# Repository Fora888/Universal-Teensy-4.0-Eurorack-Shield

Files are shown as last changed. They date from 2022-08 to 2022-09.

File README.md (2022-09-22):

# Universal-Teensy-4.0-Eurorack-Shield
This PCB is designed to piggyback onto a perfboard, to eneable easy designing and building of custom DSP based eurorack modules. It features two 24-bit audio input and two 24-bit audio output channels. The corresponding DAC and ADC are wired up to easily work with the PJRC audio library. 

## Components
All components minus the Teensy 4.0 microcontroller and PCB can be easily ordered with the mouser project below
https://www.mouser.com/ProjectManager/ProjectDetail.aspx?AccessID=7126760366

The PCB can be ordered at a PCB manufacturer of your choice. I ordered mine at Aisler.

## Building Notes
I recommend to reflow solder this board, since most pads are really close to eachother. If you however choose to handsolder, my advice is to go from smallest to largest component.

The headers on the teensy need to be on the same side as the USB port, so that the USB port faces towards the PCB when mounted. This is done to allow utilisation of the backside pins of the Teensy. There are also 5V and GND markings on the PCB to ensure correct orientation.

## Schematic
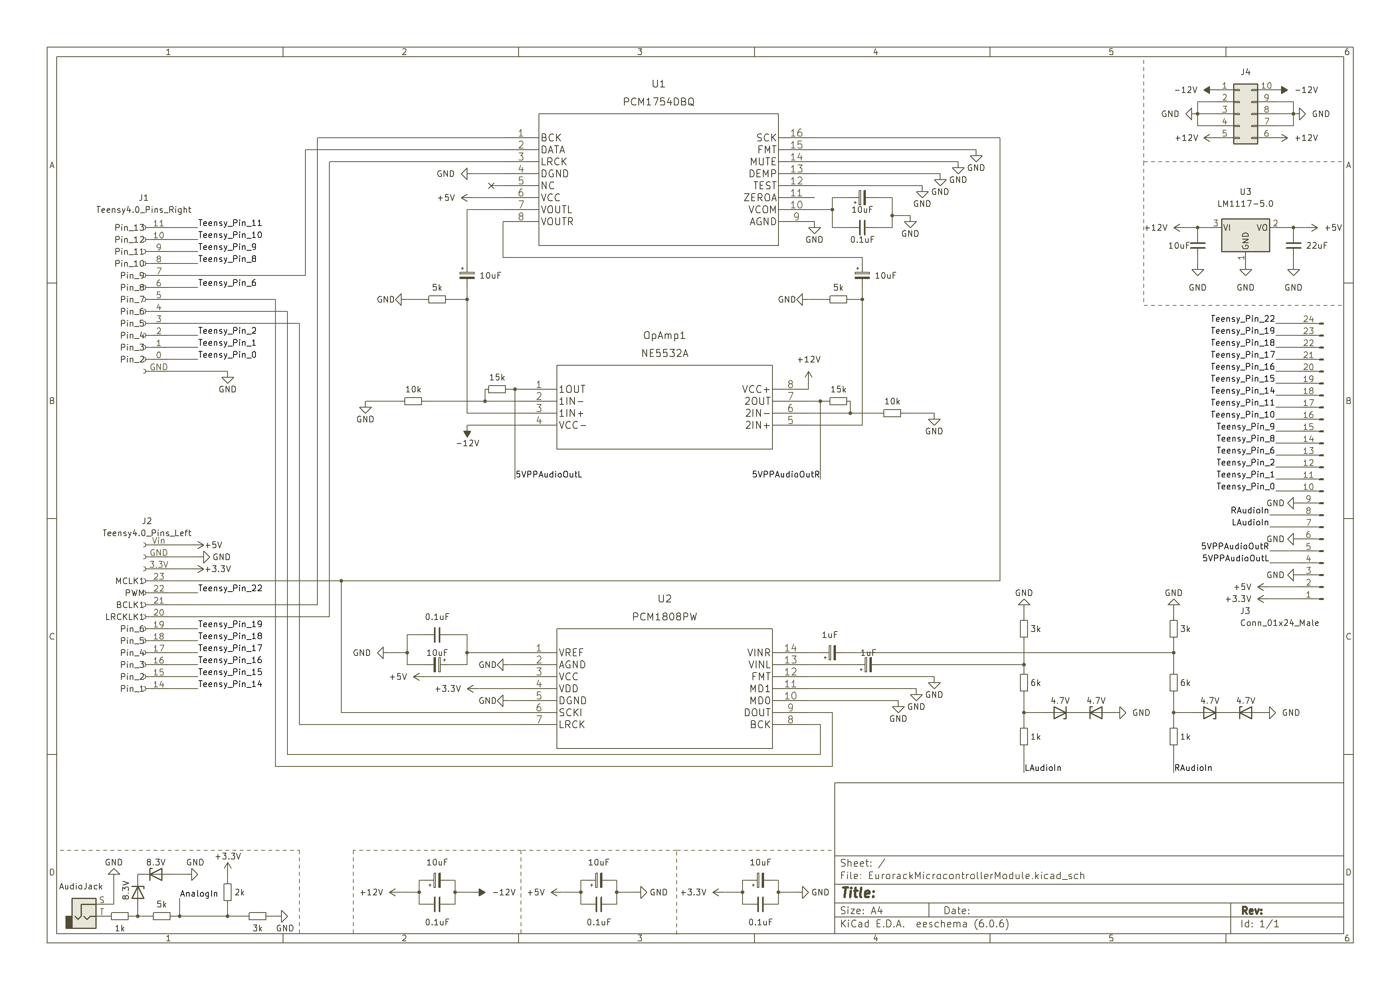
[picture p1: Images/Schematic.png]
Schematic


## 3DRender
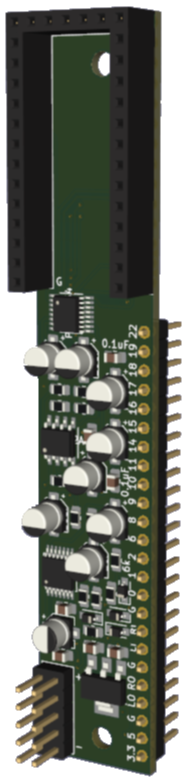
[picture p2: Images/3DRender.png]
3DRenderg


## Example Modules
There are currently no working examples. I am however working on a wavetable module based on this board. I'll add it as soon as it's finished.

## Disclaimer
The Updated PCB has yet to be build and is therefore not guaranteed to work. The last commit that was build and tested is [df5ed19](https://github.com/Fora888/Universal-Teensy-4.0-Eurorack-Shield/tree/df5ed198294865db2b968ab182dcd4eb55e7e81e)

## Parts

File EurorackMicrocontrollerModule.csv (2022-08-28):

Source: | C:\Users\Florian\Documents\KiCad\EurorackMicrocontrollerModule\EurorackMicrocontrollerModule.kicad_sch
Date: | 04.08.2022 11:55:44
Tool: | Eeschema (6.0.6)
Generator: | C:\Program Files\KiCad\6.0\bin\scripting\plugins/bom_csv_grouped_by_value.py
Component Count: | 47
Individual Components:
Item | Qty | Reference(s) | Value | LibPart | Footprint | Datasheet
 |  | C1 | 10uF | Device:C_Polarized_Small | Capacitor_SMD:CP_Elec_4x4.5 | Electrolytisch
 |  | C2 | 10uF | Device:C_Polarized_Small | Capacitor_SMD:CP_Elec_4x4.5 | Elektrolytisch
 |  | C3 | 0.1uF | Device:C_Small | Capacitor_SMD:C_0805_2012Metric_Pad1.18x1.45mm_HandSolder | ~
 |  | C4 | 10uF | Device:C_Polarized_Small | Capacitor_SMD:CP_Elec_4x4.5 | Elektrolytisch
 |  | C5 | 10uF | Device:C_Polarized_Small | Capacitor_SMD:CP_Elec_4x4.5 | Electrolytisch
 |  | C6 | 0.1uF | Device:C_Small | Capacitor_SMD:C_0805_2012Metric_Pad1.18x1.45mm_HandSolder | ~
 |  | C7 | 10uF | Device:C_Polarized_Small | Capacitor_SMD:CP_Elec_4x4.5 | Electrolytisch
 |  | C8 | 1uF | Device:C_Polarized_Small | Capacitor_SMD:CP_Elec_4x4.5 | Elektrolytisch
 |  | C9 | 1uF | Device:C_Polarized_Small | Capacitor_SMD:CP_Elec_4x4.5 | Elektrolytisch
 |  | C10 | 0.1uF | Device:C_Small | Capacitor_SMD:C_0805_2012Metric_Pad1.18x1.45mm_HandSolder | ~
 |  | C11 | 10uF | Device:C_Polarized_Small | Capacitor_SMD:CP_Elec_4x4.5 | Electrolytisch
 |  | C12 | 0.1uF | Device:C_Small | Capacitor_SMD:C_0805_2012Metric_Pad1.18x1.45mm_HandSolder | ~
 |  | C13 | 10uF | Device:C_Small | Capacitor_SMD:C_0805_2012Metric_Pad1.18x1.45mm_HandSolder | ~
 |  | C14 | 22uF | Device:C_Small | Capacitor_SMD:C_0805_2012Metric_Pad1.18x1.45mm_HandSolder | ~
 |  | C15 | 10uF | Device:C_Polarized_Small | Capacitor_SMD:CP_Elec_4x4.5 | Electrolytisch
 |  | C16 | 0.1uF | Device:C_Small | Capacitor_SMD:C_0805_2012Metric_Pad1.18x1.45mm_HandSolder | ~
 |  | D1 | 4.7V | Device:D_Zener | Diode_SMD:D_SOD-323_HandSoldering | ~
 |  | D2 | 4.7V | Device:D_Zener | Diode_SMD:D_SOD-323_HandSoldering | ~
 |  | D3 | 4.7V | Device:D_Zener | Diode_SMD:D_SOD-323_HandSoldering | ~
 |  | D4 | 4.7V | Device:D_Zener | Diode_SMD:D_SOD-323_HandSoldering | ~
 |  | D5 | 8.3V | Device:D_Zener |  | ~
 |  | D6 | 8.3V | Device:D_Zener |  | ~
 |  | J1 | Teensy4.0_Pins_Right | :Conn_01x13_Female_1 | Connector_PinSocket_2.54mm:PinSocket_1x13_P2.54mm_Vertical | ~
 |  | J2 | Teensy4.0_Pins_Left | Connector:Conn_01x13_Female | Connector_PinSocket_2.54mm:PinSocket_1x13_P2.54mm_Vertical | ~
 |  | J3 | Conn_01x24_Male | Connector:Conn_01x24_Male | Connector_PinHeader_2.54mm:PinHeader_1x24_P2.54mm_Vertical | ~
 |  | J4 | Conn_02x05_Counter_Clockwise | Connector_Generic:Conn_02x05_Counter_Clockwise | Connector_PinHeader_2.54mm:PinHeader_2x05_P2.54mm_Vertical | ~
 |  | J5 | AudioJack | Connector:AudioJack2 |  | ~
 |  | OpAmp1 | NE5532A | NE5534A:NE5532AD | NE5534A:NE5532AD
 |  | R1 | 10k | Device:R_Small | Resistor_SMD:R_0805_2012Metric_Pad1.20x1.40mm_HandSolder | ~
 |  | R2 | 15k | Device:R_Small | Resistor_SMD:R_0805_2012Metric_Pad1.20x1.40mm_HandSolder | ~
 |  | R3 | 10k | Device:R_Small | Resistor_SMD:R_0805_2012Metric_Pad1.20x1.40mm_HandSolder | ~
 |  | R4 | 15k | Device:R_Small | Resistor_SMD:R_0805_2012Metric_Pad1.20x1.40mm_HandSolder | ~
 |  | R5 | 5k | Device:R_Small | Resistor_SMD:R_0805_2012Metric_Pad1.20x1.40mm_HandSolder | ~
 |  | R6 | 5k | Device:R_Small | Resistor_SMD:R_0805_2012Metric_Pad1.20x1.40mm_HandSolder | ~
 |  | R7 | 3k | Device:R_Small | Resistor_SMD:R_0805_2012Metric_Pad1.20x1.40mm_HandSolder | ~
 |  | R8 | 6k | Device:R_Small | Resistor_SMD:R_0805_2012Metric_Pad1.20x1.40mm_HandSolder | ~
 |  | R9 | 1k | Device:R_Small | Resistor_SMD:R_0805_2012Metric_Pad1.20x1.40mm_HandSolder | ~
 |  | R10 | 3k | Device:R_Small | Resistor_SMD:R_0805_2012Metric_Pad1.20x1.40mm_HandSolder | ~
 |  | R11 | 6k | Device:R_Small | Resistor_SMD:R_0805_2012Metric_Pad1.20x1.40mm_HandSolder | ~
 |  | R12 | 1k | Device:R_Small | Resistor_SMD:R_0805_2012Metric_Pad1.20x1.40mm_HandSolder | ~
 |  | R13 | 1k | Device:R_Small |  | ~
 |  | R14 | 5k | Device:R_Small |  | ~
 |  | R15 | 2k | Device:R_Small |  | ~
 |  | R16 | 3k | Device:R_Small |  | ~
 |  | U1 | PCM1754DBQ | PCM1754DBQR:PCM1754DBQ | PCM1754DBQR:PCM1754DBQ
 |  | U2 | PCM1808PW | PCM1808:PCM1808PW | PCM1808:PCM1808PW
 |  | U3 | AZ1117H2-ADJ | Regulator_Linear:AZ1117H-ADJ | Package_TO_SOT_SMD:SOT-223-3_TabPin2 | https://www.diodes.com/assets/Datasheets/products_inactive_data/AZ1117.pdf
Collated Components:
Item | Qty | Reference(s) | Value | LibPart | Footprint | Datasheet
1 | 7 | C1, C2, C4, C5, C7, C11, C15 | 10uF | Device:C_Polarized_Small | Capacitor_SMD:CP_Elec_4x4.5 | Electrolytisch
2 | 5 | C3, C6, C10, C12, C16 | 0.1uF | Device:C_Small | Capacitor_SMD:C_0805_2012Metric_Pad1.18x1.45mm_HandSolder | ~
3 | 2 | C8, C9 | 1uF | Device:C_Polarized_Small | Capacitor_SMD:CP_Elec_4x4.5 | Elektrolytisch
4 | 1 | C13 | 10uF | Device:C_Small | Capacitor_SMD:C_0805_2012Metric_Pad1.18x1.45mm_HandSolder | ~
5 | 1 | C14 | 22uF | Device:C_Small | Capacitor_SMD:C_0805_2012Metric_Pad1.18x1.45mm_HandSolder | ~
6 | 4 | D1, D2, D3, D4 | 4.7V | Device:D_Zener | Diode_SMD:D_SOD-323_HandSoldering | ~
7 | 2 | D5, D6 | 8.3V | Device:D_Zener |  | ~
8 | 1 | J1 | Teensy4.0_Pins_Right | :Conn_01x13_Female_1 | Connector_PinSocket_2.54mm:PinSocket_1x13_P2.54mm_Vertical | ~
9 | 1 | J2 | Teensy4.0_Pins_Left | Connector:Conn_01x13_Female | Connector_PinSocket_2.54mm:PinSocket_1x13_P2.54mm_Vertical | ~
10 | 1 | J3 | Conn_01x24_Male | Connector:Conn_01x24_Male | Connector_PinHeader_2.54mm:PinHeader_1x24_P2.54mm_Vertical | ~
11 | 1 | J4 | Conn_02x05_Counter_Clockwise | Connector_Generic:Conn_02x05_Counter_Clockwise | Connector_PinHeader_2.54mm:PinHeader_2x05_P2.54mm_Vertical | ~
12 | 1 | J5 | AudioJack | Connector:AudioJack2 |  | ~
13 | 1 | OpAmp1 | NE5532A | NE5534A:NE5532AD | NE5534A:NE5532AD
14 | 2 | R1, R3 | 10k | Device:R_Small | Resistor_SMD:R_0805_2012Metric_Pad1.20x1.40mm_HandSolder | ~
15 | 2 | R2, R4 | 15k | Device:R_Small | Resistor_SMD:R_0805_2012Metric_Pad1.20x1.40mm_HandSolder | ~
16 | 2 | R5, R6 | 5k | Device:R_Small | Resistor_SMD:R_0805_2012Metric_Pad1.20x1.40mm_HandSolder | ~
17 | 2 | R7, R10 | 3k | Device:R_Small | Resistor_SMD:R_0805_2012Metric_Pad1.20x1.40mm_HandSolder | ~
18 | 2 | R8, R11 | 6k | Device:R_Small | Resistor_SMD:R_0805_2012Metric_Pad1.20x1.40mm_HandSolder | ~
19 | 2 | R9, R12 | 1k | Device:R_Small | Resistor_SMD:R_0805_2012Metric_Pad1.20x1.40mm_HandSolder | ~
20 | 1 | R13 | 1k | Device:R_Small |  | ~
21 | 1 | R14 | 5k | Device:R_Small |  | ~
22 | 1 | R15 | 2k | Device:R_Small |  | ~
23 | 1 | R16 | 3k | Device:R_Small |  | ~
24 | 1 | U1 | PCM1754DBQ | PCM1754DBQR:PCM1754DBQ | PCM1754DBQR:PCM1754DBQ
25 | 1 | U2 | PCM1808PW | PCM1808:PCM1808PW | PCM1808:PCM1808PW
26 | 1 | U3 | AZ1117H2-ADJ | Regulator_Linear:AZ1117H-ADJ | Package_TO_SOT_SMD:SOT-223-3_TabPin2 | https://www.diodes.com/assets/Datasheets/products_inactive_data/AZ1117.pdf

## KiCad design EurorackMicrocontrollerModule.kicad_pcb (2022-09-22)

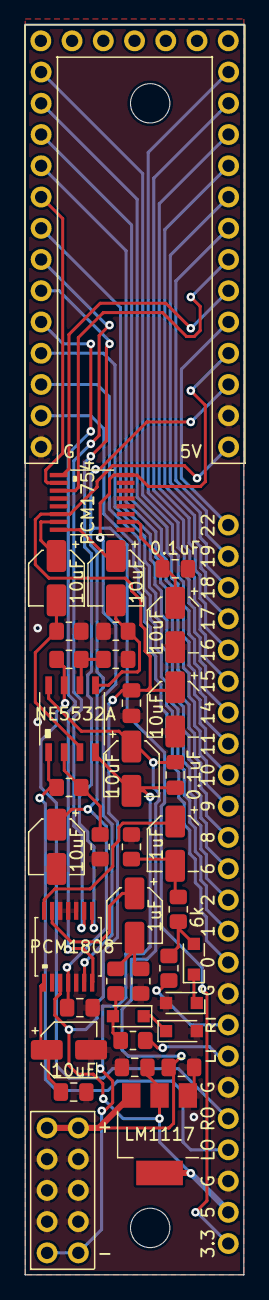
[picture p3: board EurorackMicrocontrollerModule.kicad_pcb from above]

Board: 2 copper layers, 17.8 x 101.6 mm, 41 parts (1 on the bottom side), 47 nets.

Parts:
C1, C2, C4, C5, C7, C11, C15: 10uF; CP_Elec_4x4.5
C3, C6, C10, C12, C16: 0.1uF; C_0805_2012Metric_Pad1.18x1.45mm_HandSolder
C8, C9: 1uF; CP_Elec_4x4.5
C13: 10uF; C_0805_2012Metric_Pad1.18x1.45mm_HandSolder
C14: 22uF; C_0805_2012Metric_Pad1.18x1.45mm_HandSolder
D1, D2, D3, D4: 4.7V; D_SOD-323_HandSoldering
J1: Teensy4.0_Pins_Right; PinSocket_1x13_P2.54mm_Vertical
J2: Teensy4.0_Pins_Left; PinSocket_1x13_P2.54mm_Vertical
J3: Conn_01x24_Male; PinHeader_1x24_P2.54mm_Vertical
J4: Conn_02x05_Counter_Clockwise; PinHeader_2x05_P2.54mm_Vertical
J5: Teensy4.0_Pins_Top; PinSocket_1x07_P2.54mm_Vertical
OpAmp1: NE5532A; NE5532AD
R1, R3: 10k; R_0805_2012Metric_Pad1.20x1.40mm_HandSolder
R2, R4: 15k; R_0805_2012Metric_Pad1.20x1.40mm_HandSolder
R5, R6: 5k; R_0805_2012Metric_Pad1.20x1.40mm_HandSolder
R7, R10: 3k; R_0805_2012Metric_Pad1.20x1.40mm_HandSolder
R8, R11: 6k; R_0805_2012Metric_Pad1.20x1.40mm_HandSolder
R9, R12: 1k; R_0805_2012Metric_Pad1.20x1.40mm_HandSolder
U1: PCM1754DBQ
U2: PCM1808PW
U3: LM1117-5.0; SOT-223-3_TabPin2

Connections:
+3.3V: C11.1, C12.1, J2.3.3V, J3.1, U2.4 (VDD)
+5V: C5.1, C6.1, C14.1, J2.Vin, J3.2, U1.6 (VCC), U2.3 (VCC), U3.2 (VO)
+12V: C1.1, C3.1, C13.1, J4.5, J4.6, OpAmp1.8 (VCC+), U3.3 (VI)
-12V: C1.2, C3.2, J4.1, J4.10, OpAmp1.4 (VCC-)
/5VPPAudioOutL: J3.4, OpAmp1.1 (1OUT), R2.2
/5VPPAudioOutR: J3.5, OpAmp1.7 (2OUT), R4.1
/LAudioIn: J3.7, R9.2
/RAudioIn: J3.8, R12.2
/Teensy_Pin_0: J1.0 (Pin_2), J3.10
/Teensy_Pin_1: J1.1 (Pin_3), J3.11
/Teensy_Pin_2: J1.2 (Pin_4), J3.12
/Teensy_Pin_6: J1.6 (Pin_8), J3.13
/Teensy_Pin_8: J1.8 (Pin_10), J3.14
/Teensy_Pin_9: J1.9 (Pin_11), J3.15
/Teensy_Pin_10: J1.10 (Pin_12), J3.16
/Teensy_Pin_11: J1.11 (Pin_13), J3.17
/Teensy_Pin_14: J2.14 (Pin_1), J3.18
/Teensy_Pin_15: J2.15 (Pin_2), J3.19
/Teensy_Pin_16: J2.16 (Pin_3), J3.20
/Teensy_Pin_17: J2.17 (Pin_4), J3.21
/Teensy_Pin_18: J2.18 (Pin_5), J3.22
/Teensy_Pin_19: J2.19 (Pin_6), J3.23
/Teensy_Pin_22: J2.22 (PWM), J3.24
GND: C5.2, C6.2, C7.2, C10.1, C11.2, C12.2, C13.2, C14.2, C15.2, C16.1, D2.2 (A), D4.2 (A), J1.GND, J2.GND, J3.3, J3.6, J3.9, J4.2, J4.3, J4.4, J4.7, J4.8, J4.9, R1.1, R3.2, R5.1, R6.1, R7.1, R10.1, U1.4 (DGND), U1.9 (AGND), U1.12 (TEST), U1.13 (DEMP), U1.14 (MUTE), U1.15 (FMT), U2.2 (AGND), U2.5 (DGND), U2.10 (MD0), U2.11 (MD1), U2.12 (FMT), U3.1 (ADJ)
unnamed: C2.1, U1.7 (VOUTL)
unnamed: C2.2, OpAmp1.3 (1IN+), R5.2
unnamed: C4.1, U1.8 (VOUTR)
unnamed: C4.2, OpAmp1.5 (2IN+), R6.2
unnamed: C8.1, U2.14 (VINR)
unnamed: C8.2, R10.2, R11.1
unnamed: C9.1, U2.13 (VINL)
unnamed: C9.2, R7.2, R8.1
unnamed: C7.1, C10.2, U2.1 (VREF)
unnamed: C15.1, C16.2, U1.10 (VCOM)
unnamed: D1.1 (K), D2.1 (K)
unnamed: D1.2 (A), R8.2, R9.1
unnamed: D3.1 (K), D4.1 (K)
unnamed: D3.2 (A), R11.2, R12.1
unnamed: J1.3 (Pin_5), U2.7 (LRCK)
unnamed: J1.4 (Pin_6), U2.8 (BCK)
unnamed: J1.5 (Pin_7), U2.9 (DOUT)
unnamed: J1.7 (Pin_9), U1.2 (DATA)
unnamed: J2.20 (LRCKLK1), U1.3 (LRCK)
unnamed: J2.21 (BCLK1), U1.1 (BCK)
unnamed: J2.23 (MCLK1), U1.16 (SCK), U2.6 (SCKI)
unnamed: OpAmp1.2 (1IN-), R1.2, R2.1
unnamed: OpAmp1.6 (2IN-), R3.1, R4.2

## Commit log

2022-08-28 images for Readme
    [EurorackMicrocontrollerModule.kicad_pcb]
2022-09-01 Changed LDO pad layout to a more common one
    [EurorackMicrocontrollerModule.kicad_pcb, EurorackMicrocontrollerModule.kicad_sch]
2022-09-22 Shortened PCB and moved top Screw hole; Added pin labels; Moved capacitor near power plug
    [EurorackMicrocontrollerModule.kicad_pcb]

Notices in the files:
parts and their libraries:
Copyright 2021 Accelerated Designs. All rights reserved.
